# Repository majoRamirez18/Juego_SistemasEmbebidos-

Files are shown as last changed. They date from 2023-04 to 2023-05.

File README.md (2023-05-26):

# Juego_SistemasEmbebidos-

Bienvenido al nuestro repositorio de juego con leds como proyecto de la materia Sistemas embebidos.
Como puedes observar vas a encontrar varios archivos en este repositorio que muestran su significado a continuación.

1. Materiales.csv. En este archivo vas a encontrar la lista de materiales que usamos y el costo de los mismos

2. Carpeta llamada "Estructura del hardware". Aquí encontraras los pdf´s que muestran la estructura física del hardware de este sistema embebido. Además de que encontraras los archivos originales de esta estructura que se hizo con ayuda de un software llamado KiCad. Los importantes son: 
- Juego (parte 1) primeras 2 filas de leds y botones.pdf
- Juego (parte 2) siguientes 2 filas de leds .pdf

3. Carpeta llamada “Código”. Aquí encontraras el código del juego versión 1 que se uso en nuestro sistema embebido.
El archivo es un Arduino file pues se usó el IDE de Arduino para poder programar su función y también lo encontraras elaborado en platformio.

Antes de iniciar con este proyecto se tiene que mencionar que es la creación de un sistema embebido muy básico y para poder hacerlo es importante que se tengan conceptos básicos de electrónica como lo son: manejo de voltajes, pull down, pull up, manejo de resistencias, calcular la resistencia de un led con voltaje o de un botón, entre otros. Además que mas adelante también debes de saber sobre programación básica y el manejo de bits para entender un poco de cómo funciona el programa.
Una vez mencionado esto vamos a hacer el paso a paso el proyecto.

# Descripción general del proyecto.
El proyecto trata de un juego inspirándonos en un bark game. Hicimos desde cero una pantalla de leds 8x8 usando registros de desplazamiento por cada una de las filas para controlar los leds y hacer un control muy básico que se maneja por voltaje para que se pueda mover en este caso el personaje del juego que se representa con un led.
							


## Materiales.
Lo primero es comprar los materiales. Estos podrás encontrarlos en el archivo Excel en este repositorio.

### Entendiendo la estructura del hardware.
La estructura del hardware del proyecto fue elaborado en kitcad en donde se presentan todos los materiales que se van a usar de la mejor manera.
Consulta los PDFs dentro de la carpeta estructura de hardware.

El pdf del Juego (parte 1) primeras 2 filas de leds y botones.pdf es el esquema de la primera parte del juego que son los botones y las primeras dos filas de leds conectados a un registro de desplazamiento

El pdf del Juego (parte 2) siguiente 2 filas de leds.pdf es la otra parte faltante del esquema del juego que son las demás filas (seis) de la matriz a formar.

Con estos esquemas te puedes guiar para saber cómo irán cada uno de los componentes electrónicos: leds, resistencias, arduino, botones y registros de desplazamiento. Te recomendamos buscar el símbolo electrónico de cada componente si no estas familiarizado con el mismo.

# 1. Pasos
## 1.1	Soldar los sockets para los leds y para los registros de desplazamiento.
En esta sección se adquirieron sockets para facilitar la colocación de los LEDs, ya que cada placa perforada tiene dos hileras de 8 LEDs. Además, se soldaron las resistencias de cada hilera para evitar que se crucen y se dispongan en diferentes direcciones.


## 1.2	 Soldar los cables para los leds hacia los registros de desplazamiento
Soldamos los cables de cada LED cuidando que a la patita del led en la cual soldamos los cables sea la más grande pues es (+), la otra patita es la mas pequeña (-) la cual es la de tierra y por ende irán las resistencias conectadas a esa patita pequeña.
Para esto también te explicamos los registros de desplazamiento que tienen la siguiente estructura:


Como se ve son 16 entradas las que se tienen. Las patillas desde Q0 a Q7 son en donde se van a soldar la otra parte de los cables pues estas patitas van a mandar información a los leds. La que se conecte a Q0 es el led mas importante procura que sea el primero empezando de tu lado izquierdo.
Y las tres entradas que irán conectadas a las salidas de nuestra placa de Arduino son DS (patilla 2), STCP (patilla 3) y SHCP (patilla 4).

Retomando lo anterior los cables conectados al led de la patita más larga irán al registro de desplazamiento, comenzando desde el exterior y avanzando hacia el interior, siguiendo el diagrama del proyecto.
WhatsApp Image 2023-05-03 at 5 20 27 PM


## 1.3	Soldar las resistencias y puentear a tierra
Las resistencias que ya están soldadas a la patita del led están bien. El otro lado de las resistencias las vamos a conectar entre ellas como en fila. Esto se le llama puentear a tierra pues la última resistencia que se soldé va a ir a tierra conectada.
WhatsApp Image 2023-05-03 at 5 21 08 PM

## 1.4	Soldar las entradas de voltaje de los registros de desplazamiento hacia voltaje y las entradas de tierra hacia tierra
En este paso te pedimos que pongas atención


Hay que identificar los pines de corriente y de tierra, para ello checa la siguiente imagen.


Los cables negros son tierra y los cables rojos son corriente. En el prototipo conectarlas de esta forma.

## 1.5	Pin data, latch y clock
Cada placa contiene 2 registros el data, latch y clock se conectan entre sí de cada registro


Los pines son los cables de color: azul, verde y amarillo. Si los conectamos entre si se vería de la siguiente manera


De forma física debió de quedarte así



## 1.6 Repetir, repetir y repetir.
El mismo proceso hay que hacerlo por 3 veces para que obtengas tu matriz de 8x8 leds.

# 2. Control

Simulación. Primero simulamos de manera virtual el circuito de la cruceta de botones.


Con la simulación virtual empezamos a medir el voltaje de cada uno de los botones con un multímetro de manera digital, los resultados fueron los siguientes:

Botones	Voltaje	Corriente	Media
Botón 1 (A)	4V	817	
Botón 2 (B)	3V	613	204
Botón 3 (C)	2V	408	205
Botón 4 (D)	1V	204	204
Tabla 1 voltaje de los botones

Sacamos la moda que es 204, partiendo de ello sacamos la medida dividiéndola entre 6 para tener un límite de voltaje de cada botón y así no se confunda el usuario al momento apretar uno u otro botón.
 

Definir el límite de voltaje. Como se ve en la ilustración 3 los límites de cada botón no se topan uno con el otro por lo que la medida de dividirlo entre 6 nos va a beneficiar. 
Codificamos el programa. Los comentarios lo explican:



## 2.1 Elementos.
Preparamos los elementos físicos ya adecuados teniendo consideraciones y los colocamos en la placa antes de soldarlos para tener una idea.
 

Va a ver 3 alambres sueltos los cuales son: la corriente que se conectara al pin de 5 volts, uno de tierra que se conectara al GND del Arduino y el ultimo al pin 2 que es la entrada analógica del Arduino



Como se ve el alambre de corriente inicia conectándose a una resistencia, del otro lado de la resistencia se conecta al botón, del botón a otra resistencia y así hasta que la última resistencia se va a conectar a tierra.
En la tierra se conectará la resistencia de 1M de ahí al último botón puesto, después de ese botón a otro y así hasta que llego al alambre del pin analógico.

## 2.2 Soldar
Se empezaron a soldar todos los componentes en la placa fenólica.



## 2.3 Probar.
Una vez todo preparado se cargó el programa en el Arduino y se probó. Cada salida se conectó en su lugar correspondiente, la primera de lado derecho de la imagen es el del voltaje conectado al pin 5V de Arduino, el segundo es el de tierra y el tercero fue el analógico.
Esto es solo prueba para ver que se hizo correctamente



# 3. Montar todo.
Tenemos el botón y la matriz. Montamos todo en la arduino.
WhatsApp Image 2023-05-03 at 5 53 33 PM
WhatsApp Image 2023-05-24 at 12 29 00 AM

# 3.1 Programa

Dentro de la carpeta de código podremos encontrar el código del proyecto en dos versiones:
1. Arduino. Usa el IDE de arduino, conecta tu arduino y carga el código del proyecto
2. Platformio. Usa Visual Studio Code y descarga la extensión de platformio, carga el proyecto y listo. Sino también puede hacerlo en forma de cmd.

# 4. Consideraciones finales.

Puede alimentar el proyecto con una batería de 5 volts o con tu computadora. Si tienes alguna duda no dudes en escribirnos y te ayudaremos lo antes posible.

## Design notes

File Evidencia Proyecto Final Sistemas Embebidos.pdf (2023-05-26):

Instituto Tecnológico de San Juan del Río

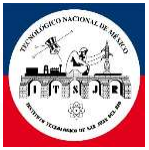
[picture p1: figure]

Av. Tecnológico # 2, C.P. 76800, San Juan del Río, Querétaro, México
www.tecnm.m x | www.itsanjuan.edu.mx

# Instituto Tecnológico de San Juan del Río

## SISTEMAS EMBEBIDOS

# Reporte de exposición final proyecto “Juego de

# leds”

### P R E S E N T A:

## María José Ramírez Basilio

## Evelyn Hernández Martínez

## José Alfredo Jiménez Terreros

## Tecnologías de la información y comunicación

## San Juan del Río, Qro., 26 de mayo del 2023

Av. Tecnológico # 2, C.P. 76800, San Juan del Río, Querétaro, México

Contenido
Índice de ilustraciones | 2
Juego de leds Matrix | 3
Fotos tomadas durante la exposición | 4
Experiencia de cada uno de los integrantes | 5
Evelyn | 5
Maria Jose | 6
Alfredo | 6

Índice de ilustraciones.

Ilustración 1 Proyecto | 3
Ilustración 2 Fotos de la exposición | 4
Ilustración 3 Foto de la exposición | 4
Ilustración 4 Evidencia | 5

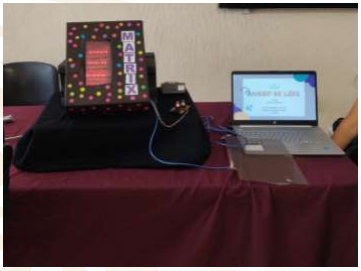
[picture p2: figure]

Av. Tecnológico # 2, C.P. 76800, San Juan del Río, Querétaro, México

Juego de leds Matrix.

El día 24 de mayo del 2023 a las 10:00

am se llevó a cabo la exposición de

nuestro proyecto final de la materia de

sistemas embebidos el cual lo llamamos

MATRIX-

Nuestro público en la exposición vario

pero el objetivo fueron alumnos del

Cecytec quienes algunos se mostraron

interesados en el proyecto además de

que atendimos las dudas que tenían

sobre lo que les explicamos y otras que

surgían por como habíamos logrado un proyecto así y nuestras experiencias.

El objetivo de esta exposición y de nosotros fue apoyar e inspirar a los alumnos para la futura toma

de decisión de su carrera universitaria además de orientarlos referente a nuestra carrera de

Tecnologías de la Información haciendo promoción de la misma.

Durante toda la exposición nos apoyamos en material visual y también práctico que en este caso

fue una presentación y el proyecto físicamente. Conforme les explicábamos el proyecto les

mostrábamos algunas imágenes en la presentación y para el proyecto les pedíamos que se acercaran

y probaran con sus propias manos el juego siempre diciéndoles como era su función.

Al finalizar también les brindamos el repositorio de este proyecto con el objetivo de orillarlos y

sembrarles curiosidad en hacerlo o probarlo.
LINK | PRESENTACIÓN:

https://www.canva.com/design/DAFjDmu6p1A/d2mi7P6_xxnaxZerY8v-

Ilustración 1 Proyecto

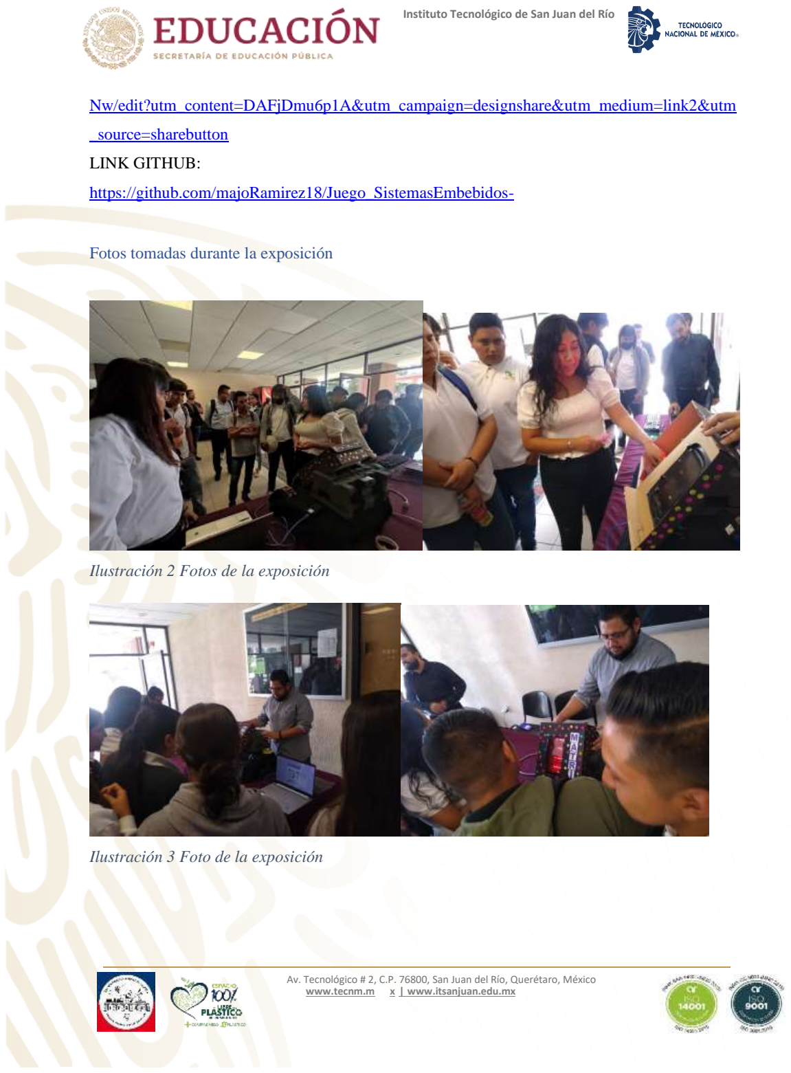
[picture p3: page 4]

Av. Tecnológico # 2, C.P. 76800, San Juan del Río, Querétaro, México

Nw/edit?utm_content=DAFjDmu6p1A&utm_campaign=designshare&utm_medium=link2&utm

_source=sharebutton (https://www.canva.com/design/DAFjDmu6p1A/d2mi7P6_xxnaxZerY8v-Nw/edit)

LINK GITHUB:

https://github.com/majoRamirez18/Juego_SistemasEmbebidos-

Fotos tomadas durante la exposición

Ilustración 2 Fotos de la exposición

Ilustración 3 Foto de la exposición

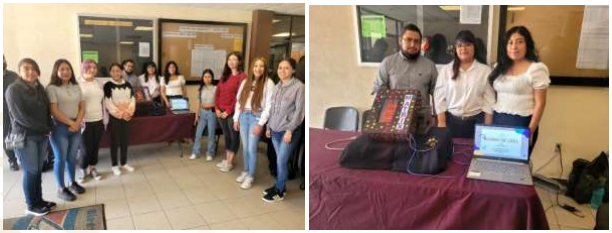
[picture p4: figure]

Av. Tecnológico # 2, C.P. 76800, San Juan del Río, Querétaro, México

Ilustración 4 Evidencia

Experiencia de cada uno de los integrantes.

Evelyn

En lo personal fue una muy buena experiencia el haber presentado a otros el proyecto en el que

nos enfocamos durante todo el semestre además de que me gustó mucho el tratar de inspirar a los

alumnos de preparatoria el que se interesaran en nuestra carrera pues es una buena carrera que

necesita mucha más difusión en las preparatorias.

Algunos se mostraban interesados y otros no tanto pero durante la presentación les preguntaba y

les explicaba cosas de manera que se sintieran interesados o con curiosidad de la funcionalidad del

proyecto. Gracias a esto a algunos les intereso otros no tanto pero el ver que muchos les sorprendió

el cablerío que teníamos además del tamaño del código con el que funcionaba el proyecto fue

grato.

Además de los alumnos de preparatoria también compañeros del mismo tecnológico de otras

carreras se mostraron interesados en lo que habíamos trabajado, nos preguntaban sobre los

componentes que habíamos usado, como funcionaban además de que con algunos compartí

experiencias parecidas las cuales me dieron la oportunidad de aprender algo nuevo.

Como ultimo comentario quiero agregar que me estrese un poco al inicio pues antes de la

presentación nos reunimos una hora antes porque hubo detalles de último momento que no hacían

Av. Tecnológico # 2, C.P. 76800, San Juan del Río, Querétaro, México funcionar el proyecto de la mejor manera como el que algunos leds ya fallaban, algunos cables de

habían torcido más.

También aprendimos que no debemos usar Resistol en los circuitos porque contiene agua y no

permite que funcione de manera adecuada.

María José

Mi experiencia el día de ayer en la exposición de nuestro proyecto “MATRIX” fue un desafío

inesperado e intrigante ya que al inicio inicialmente sentí nervios y un poco de ansiedad. Sin

embargo, a medida que comencé a hablar y a conectar con los estudiantes, esa tensión se fue

disipando.

Los estudiantes de la preparatoria CECYTEQ y algunos del TEC nos dieron opiniones y

perspectivas muy buenas de nuestro proyecto, aunque algunos alumnos de preparatoria no nos

ponían atención ya que no les gustaba esa área, pero la finalidad de presentar nuestro proyecto a

los chicos de prepa era para atraerlos a la carrera.

Para ser verdad este proyecto fue un desafío ya que pusimos a prueba todos nuestros conocimientos

aprendidos durante la carrera. Para mí en lo personal se me dificulto la parte de circuitos ya que

tuve errores al principio del armado, pero gracias a mis compañeros que me apoyaron comprendí

mejor esa parte.

Antes de presentar el proyecto nos pasó algo inesperado ya que el videojuego no funcionaba y la

verdad si nos espantamos, pero al final se pudo solucionar.

Alfredo

En mi experiencia fue algo enriquecedor poder platicar un momento con los alumnos de

preparatoria que nos visitaron, al poder conocer que carreras les interesaba o en el caso de que

fueran justamente la misma que la mía poder ampliar más su panorama sobre la carrera de TIC´s.

Av. Tecnológico # 2, C.P. 76800, San Juan del Río, Querétaro, México

Momentos antes de iniciar la presentación fue algo problemático, ya que como todo prototipo justo

antes de presentarlo surgieron algunos problemas menores, pero gracias a la experiencia que ya

teníamos trabajando sobre nuestros circuitos pudimos solucionar todo a tiempo.

En cuanto a la presentación se procedió a demostrar el funcionamiento del videojuego

implementado en la matriz de LEDs. Se explicaron los fundamentos de la programación del

videojuego en el arduino y cómo se utilizan los registros de desplazamiento para controlar los LEDs

de la matriz y como es que este mismo se podía alimentar con tan solo un power bank.

Por último, les compartimos un código QR con la dirección al GitHub del proyecto donde les

comentamos que podían encontrar todo lo necesario para replicar el proyecto ya que todo estaba

documentado y explicado, al final no todos estaban interesados, pero es algo lógico de entender ya

que no todos estaban interesados por una carrera en TIC´s o a fin, pero sobre todo me quedo con

el grupo que nos visitó que si estaba interesado por TIC´s ya que al final de la presentación se podía

ver en sus caras la emoción por entrar en la carrera.

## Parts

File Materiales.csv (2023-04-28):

MATERIAL | PIEZAS | PRECIO
Arduino | 1 | $136.00
Cautín de 30 W | 1 | $200.00
Header hembra de 40 pines | 9 | $36.00
Led rojo | 200 | $80.00
Paquete de cables jumpers (120 cables) | 2 | $160.00
Placa fenólica perforada de 5x10 | 9 | $126.00
Push button de 4 pines con capuchón | 4 | $40.00
Registro 74HC595 | 8 | $11.00
Resistencia de 1 Kohms | 6 | $6.00
Resistencia de 1 Mohms | 1 | $1.00
Resistencia de 330 ohms | 64 | $64.00
Socket de 16 pines | 8 | $4.00
Soldadura 60/40 | 2 (34 g) | $100.00
Kola loka goterito | 1 | $21.00
Pistola de silicon | 1 | $90.00
Barra de silicon | 2 | $14.00
Fuente pendiente a revisión | 0 | $0.00
TOTAL |  | $1,089.00

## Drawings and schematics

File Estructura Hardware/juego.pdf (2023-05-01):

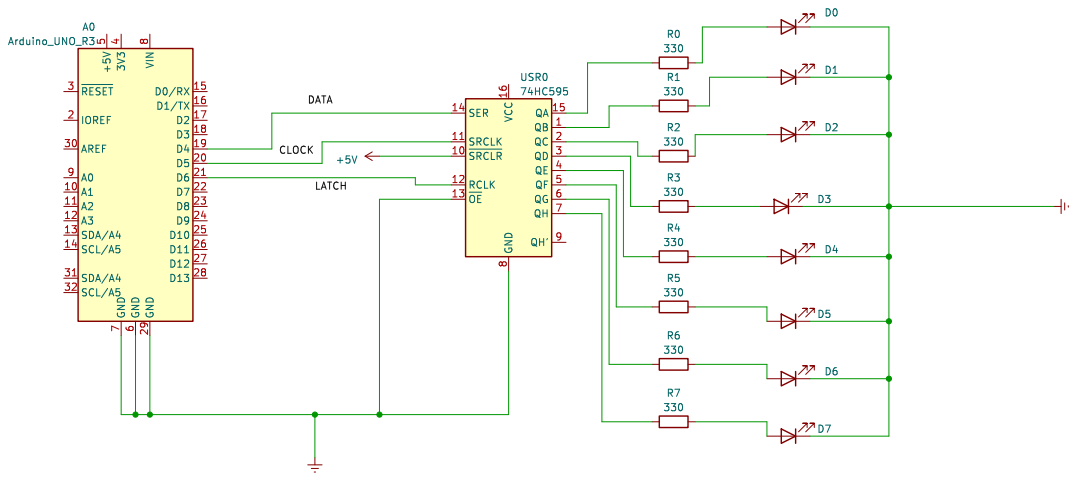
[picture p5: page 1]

Id: 1/1 Title: File: juego.kicad_sch Sheet: / R6

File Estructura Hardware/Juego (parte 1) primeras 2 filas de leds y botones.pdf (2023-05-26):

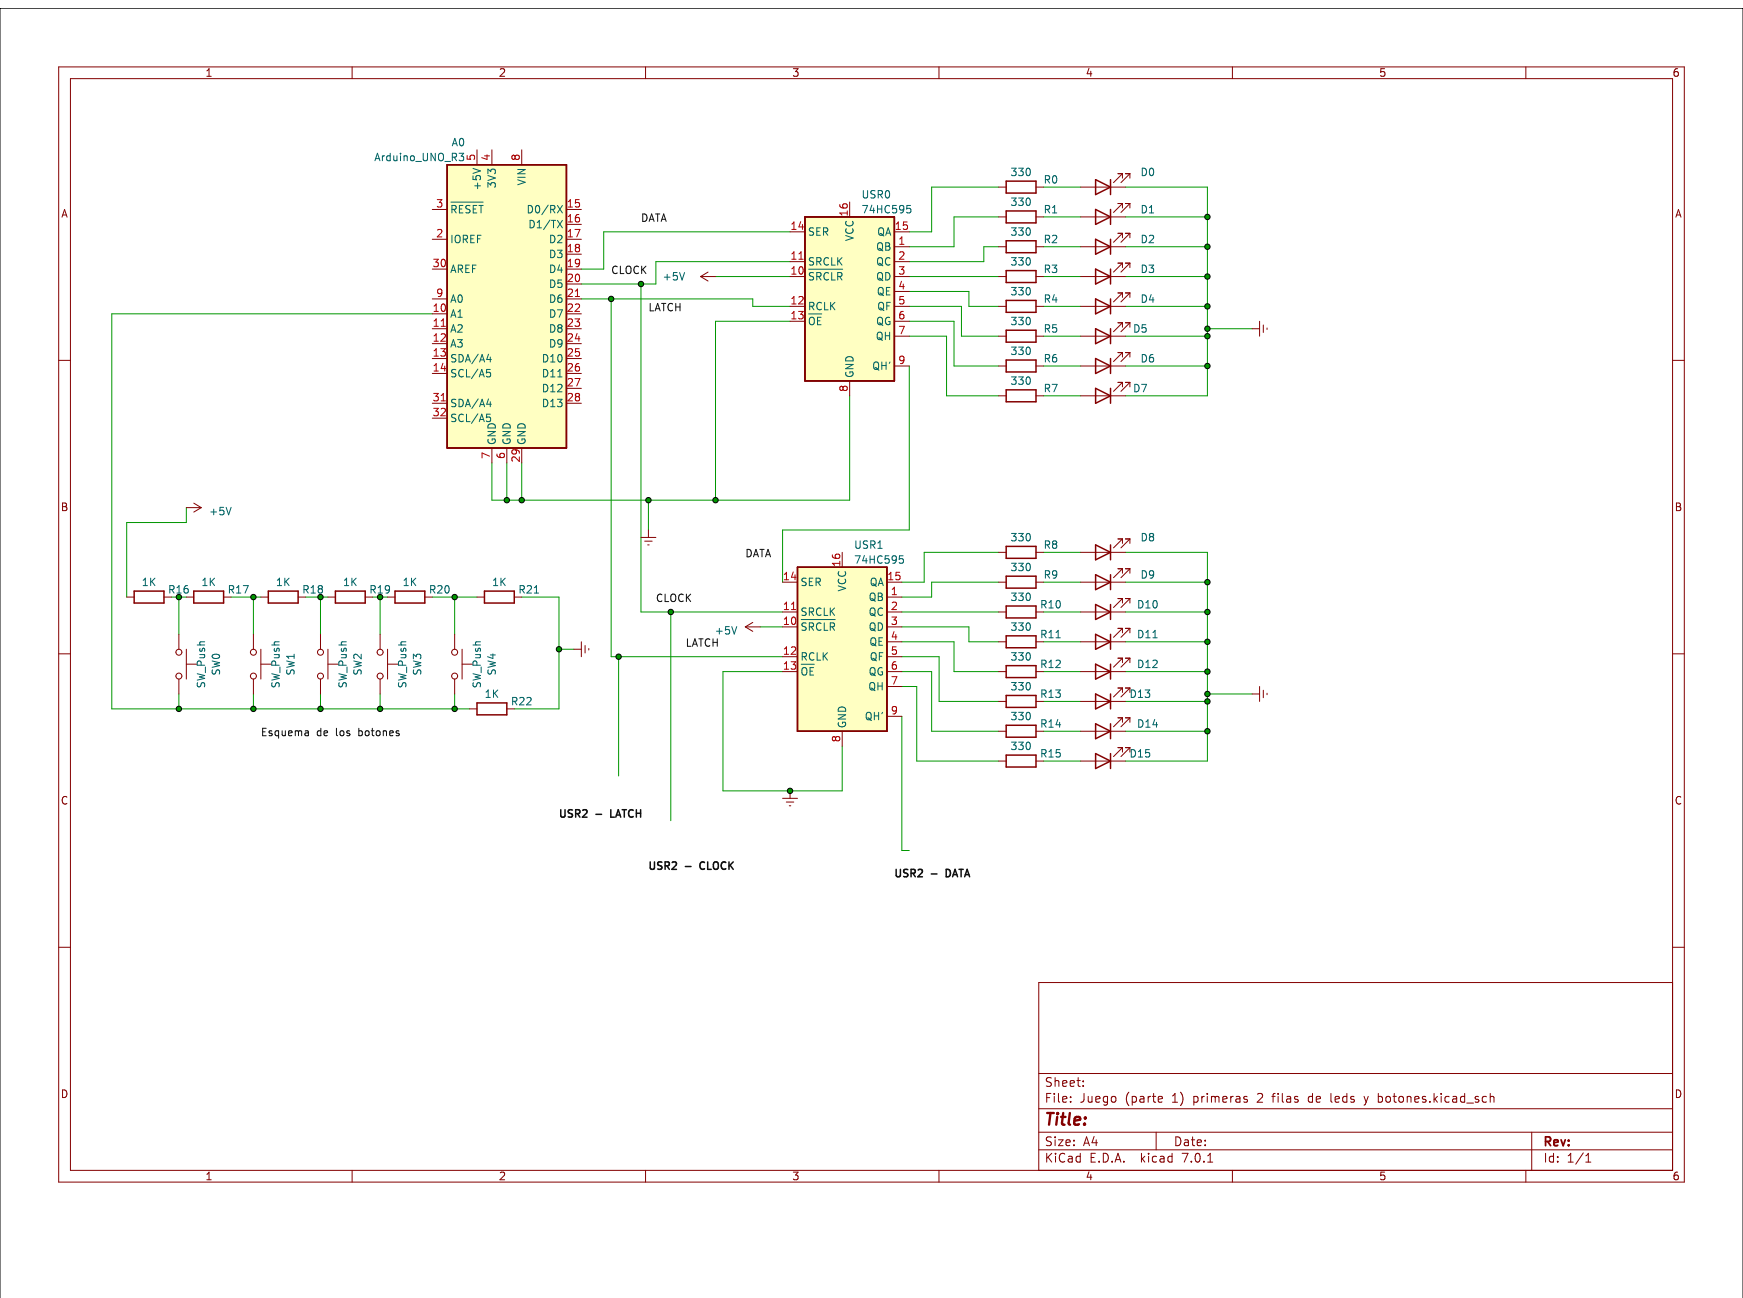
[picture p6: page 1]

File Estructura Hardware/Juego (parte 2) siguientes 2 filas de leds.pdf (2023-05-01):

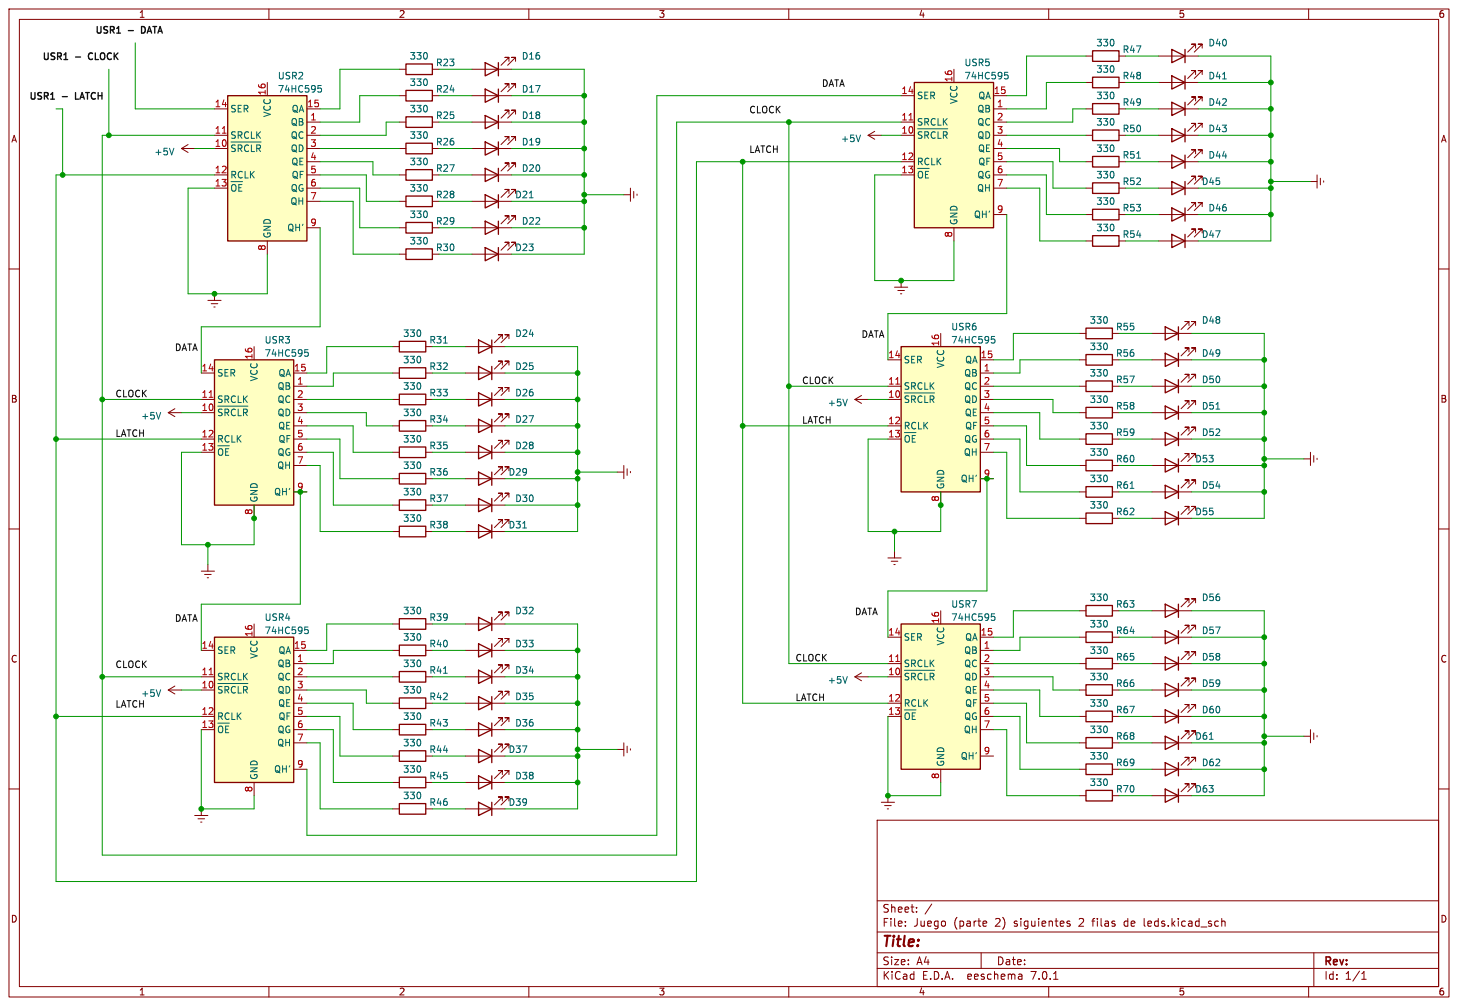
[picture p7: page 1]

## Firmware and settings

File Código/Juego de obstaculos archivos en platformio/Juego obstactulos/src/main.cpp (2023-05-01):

#include <Arduino.h>


#define DATA_PIN 4 // Pin de datos (DS) 
#define LATCH_PIN 2 // Pin de latch (ST_CP) 
#define CLOCK_PIN 3 // Pin de reloj (SH_CP)  TL 23
#define TL 28
int a[5] = {851, 681, 510, 340, 170}; //voltaje botones
byte b[5] = {16, 8, 4, 2, 1}; //valor botones
//byte bits[8] = {128, 64, 32, 16, 8, 4, 2, 1}; va así 7 a 0 en matriz
int pa=4; //inicio del numero de la columna
int arriba=0; //boton 1
int derecha=0; //boton 2
int abajo=0; //boton 3
int izquierda=0; //boton 4
int reset=0; //boton 5
int fila=7; //inicio fila actual
byte col=16; //inicio valor led bits[4]
int filapass=0; //fila con el valor anterior
byte colpass=1; //inicio valor led con el valor anterior
byte entControl = 0; //numero de control
bool valorImpreso = false; //solo para leer una vez el primer valor de un boton apretado
byte ValorA; //Es el valor anterior despues de que el led avanzara.

 

byte Mwin[8] = { //matriz de win
  B11111111, // Columna 0
  B10000001, // Columna 1
  B10000001, // Columna 2
  B10000001, // Columna 3
  B10000001, // Columna 4
  B10000001, // Columna 5
  B10000001, // Columna 6
  B11111111  // Columna 7
};

byte Mlost[8] = {
  B00000000, // Columna 0
  B10000001, // Columna 1
  B01000010, // Columna 2
  B00100100, // Columna 3
  B00011000, // Columna 4
  B00100100, // Columna 5
  B01000010, // Columna 6
  B10000001 // Columna 7 i
};

byte Minicio[8] = { //matriz de inicio
  B00000000, // Columna 0
  B00000000, // Columna 1
  B00000000, // Columna 2
  B00000000, // Columna 3
  B00000000, // Columna 4
  B00000000, // Columna 5
  B00000000, // Columna 6
  B00000000  // Columna 7
};

byte Mobs[8];  //matriz de obstaculo conforme avance el led
byte MobsO[8]; //matriz de obstaculo original


void actMwin(){ //cuando gane que matriz se va a mostrar
  for(int i=0; i<8; i++){//recorre la matriz almacenando los leds que se van a prender
    digitalWrite(LATCH_PIN , LOW);
    shiftOut(DATA_PIN, CLOCK_PIN, LSBFIRST, Mwin[i]);
  }
  digitalWrite(LATCH_PIN, HIGH); //Se prende la matriz
    delay(500);
    
}

void actMlost(){ //cuando pierda que matriz se va a mostrar
  for(int i=0; i<8; i++){//recorre la matriz almacenando los leds que se van a prender
    digitalWrite(LATCH_PIN , LOW);
    shiftOut(DATA_PIN, CLOCK_PIN, LSBFIRST, Mlost[i]);
  }
  digitalWrite(LATCH_PIN, HIGH);//Se prende la matriz
    delay(500);

}


void generarMatrizAleatoria() {
  randomSeed(analogRead(A0)); // Inicializa la semilla del generador de números aleatorios
  byte resultado; // Inicializa el byte
  int posicion; // Genera un número aleatorio entre 0 y 7
  
  for(int i=0; i<=6; i=i+2){
    resultado = 0xFF; //es un byte 11111111
    posicion = random(0, 8); //Genera un número aleatorio entre 0 y 7
    bitWrite(resultado, posicion, 0); //la variable en donde se va a escribir, el bit del numero donde se escribira, el bit que se quiere escribir
    Mobs[i]=resultado; //se almacena el bit generado
  }
    for(int i=1; i<=7; i=i+2){
    resultado = B00000000;
    Mobs[i]=resultado;
  }

  for(int i = 0; i < 8; i++) {
    MobsO[i] = Mobs[i]; //la matriz original almacena la generada para poder mover el led
    }
}

void reinicioC(){ //cuando gane se va a generar otra matriz de obstaculo diferente y se reinician los valores
  for(int i=0; i<8; i++){
    Mobs[i]=MobsO[i];
  }
  fila=7; //inicio fila
  col=16; //inicio valor led bits[4]
  filapass=0; //inicio fila
  colpass=1;
  pa=4;
  
  generarMatrizAleatoria();
}

void actMatriz(int fila, byte col){ //actualizar posición del led
   
  for(int i=0; i<8; i++){ //Se va a recorer la matriz dependiendo de como se vaya a mover el led
    if(fila == i){ //si la fila act es igual a i que es el numero de fila
       Minicio[i]=col; //la matriz en 0 se iguala al valor de la columna
      if(filapass == fila && colpass == col){ //si la fila de la posicion pasada es igual a la actual 
        // y si el valor de la columna actual es igual al de la pasada significa que 
        //filas iguales y columnas iguales, no se movio el led
        Mobs[i]=ValorA; //Se almacena el valor actual de la matriz
        }else{//fila y columna actual son diferentes
          if(Minicio[i] & Mobs[i]){ //Se compara bit por bit
            //Minicio almacena solo la posicion del led contra Mobs de los obstaculos si la posicion de led (1) resulta que en su posicion de obstaculos tambien es 1 entonces
            //ya perdio por que significa que choco con un obstaculo, se imprime la M de lost y se reinicia el juego
            
            actMlost();
            reinicioC();
          }else{ //si ningun bit es igual se combina la pisicion del led con la de los obscatulos
            Mobs[i] |= Minicio[i];            
            ValorA=Mobs[i]; //El valor actual se actualiza pues avanzo el led
            
          }
        }
        digitalWrite(LATCH_PIN , LOW);
        shiftOut(DATA_PIN, CLOCK_PIN, LSBFIRST, Mobs[i]);
       }else{// si fila y i no son iguales es decir que es el resto de la matriz
        Minicio[i]=0; //sigue en 0
        Mobs[filapass]=MobsO[filapass]; //Mobs actualiza los valores pasados con fila del Mobs original
        digitalWrite(LATCH_PIN , LOW);
        shiftOut(DATA_PIN, CLOCK_PIN, LSBFIRST, Mobs[i]); 
        }
    }
  digitalWrite(LATCH_PIN, HIGH);
    delay(200);  //Se actualiza
}



void setup() {
  // put your setup code here, to run once:
  pinMode(DATA_PIN, OUTPUT);
  pinMode(LATCH_PIN, OUTPUT);
  pinMode(CLOCK_PIN, OUTPUT);
  pinMode(A1, INPUT);
  Serial.begin(9600);
  generarMatrizAleatoria();//Se genera la matriz aleatori7a
}

void loop() {
  // put your main code here, to run repeatedly:
  int valor = 0;
  int linf = 0;
  int lsup = 0;
  int i=0;
 
   
  actMatriz(fila, col); //se actualiza la posición actual
   filapass = fila; //Se almacena como posicion pasada
  colpass = col; //Se almacena como posicion pasada
  

  
  valor = analogRead(A1); //Se lee el pin de los botones
  //Serial.println(valor);
   
  if(valor >0 && !valorImpreso){ //Si ya se leyo debe de ser false valor impreso
    valorImpreso=true; //como ya lo leyo se cambia a true
 
    for ( i = 0; i < 5; i++){ //Se recorre el valor del A1 para determinar que control es
      linf = a[i] - TL;
      lsup = a[i] + TL;
      if(valor >= linf && valor <= lsup){
        
        entControl = b[i]; 
        if(entControl == 16){
          arriba=1;//de acuerdo al valor se determina si es arriba, abajo, dere o izq o reset
          
          }else{//arr
            if(entControl == 8){
              derecha=1;
              
              }else{//de
                if(entControl == 4){
                  abajo=1;
                  
                  }else{//ab
                    if(entControl == 2){
                      izquierda=1;
                      
                      }else{
                        if(entControl == 1){
                          reset=1;
                          
                      }
                      }
                  }//iz
              }
           } // IF END BOTONES
      }
    } // FOR END
 
    if(arriba == 1){ //Se leen los valores
      if(fila > 0){//si la fila es mayor de 0 y fue arriba se disminuye
        fila--;
        
      }else{
        
       }
       if(fila == 0){//si es igual a 0 entonces ya llego a la meta 
           actMwin();
           reinicioC();
           }
       arriba = 0; //se inicia en 0 de nuevo
       valorImpreso = false; //valor impreso sera false para leer el sig movimiento

       }else{
        if(derecha == 1){
          if(col < 129 && col > 1){ //si la col es menor 129 y si es mayor a 1
            col = col >> 1; //Se disminuye el valor de columna
            pa--;
            }else{
              if(col == 1){//si col es igual a 1 entonces sera 1 para que no desaparesca de la matriz
                //De esta forma queda definido el margen ene l que entra el led
                  col = 1;
                }
            }
            derecha = 0; 
            valorImpreso = false;
            

         }else{
          if(izquierda == 1){ 
            if(col > 0 && pa < 7){//si la col es menor 0 y si pa <7 entonces pa aumentara
              pa++;
               col= 1 << pa; //Esto para almacenar el valor de la col de acuerdo a su posicion 1 << 5 = 32
               }else{
                 pa= 7; //pa sera 7 para poder respetar los limites de la matriz
                }
                izquierda = 0;
                valorImpreso = false;
                
                }else{
                  if(abajo == 1){
                    if(fila < 7){ //si la fila es menor que 7 se aumenta fila
                      fila ++;
                      }else{
                        fila = 7; //sino fila sera 7 para respetar los limites de la matriz
                        }
                        abajo = 0;
                        valorImpreso = false;
                        
                  }else{
                    if(reset==1){
                      
                      reinicioC();
                      valorImpreso = false;
                      
                      reset = 0;
                    }
                }
         }
         }
      } //IFS END
      valorImpreso = false;
  }
   
} //LOOP

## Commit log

2023-05-01 Se agrego la estructura de hardware
    [Juego (parte 1) primeras 2 filas de leds y botones.kicad_sch, Juego (parte 2) siguientes 2 filas de leds.kicad_sch, juego.kicad_pcb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]
2023-05-26 Se agrego las experiencias de la presentación
